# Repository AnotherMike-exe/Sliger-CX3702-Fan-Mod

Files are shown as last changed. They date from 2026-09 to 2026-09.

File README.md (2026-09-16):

# Sliger CX3702 - Fan Mod

*A 3D-printable front panel adaptor that adds triple 120mm fan cooling to the Sliger CX3702 (and compatible face plates).*

<table>
<tr>
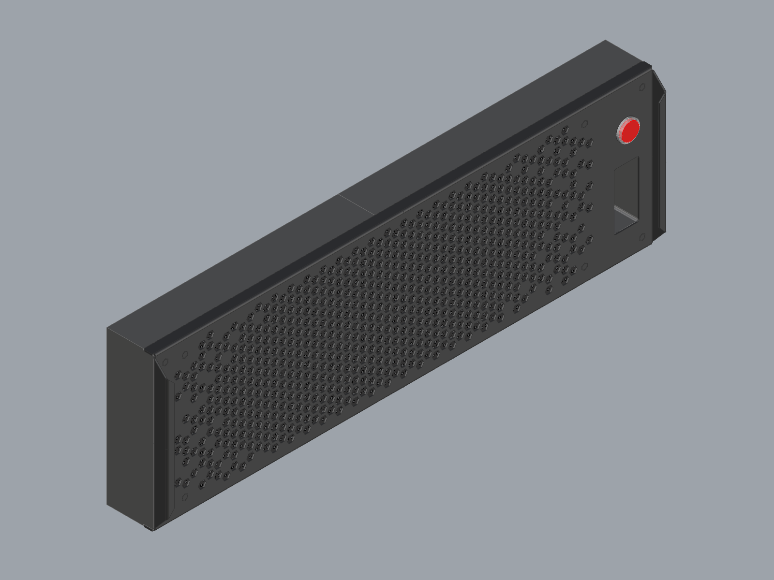
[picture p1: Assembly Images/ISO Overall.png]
Overall view of the assembled fan mod
<td></td>
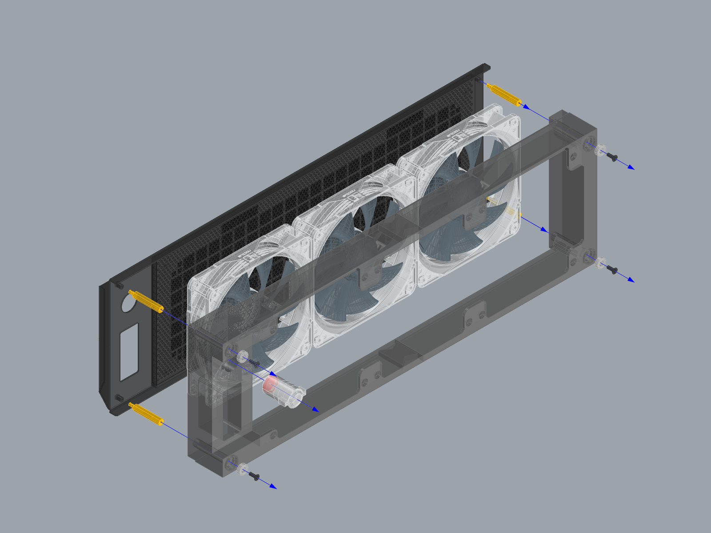
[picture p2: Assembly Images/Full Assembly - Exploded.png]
Exploded view of the full assembly
<td></td>
</tr>
</table>

## Description

This is a 3D-printable spacer for the Sliger CX3702 front panel (and any
Sliger chassis sharing the same face plate and magnetic-washer mounting system). It
allows mounting three 120mm fans, for additional airflow.

## Usage

**Print settings:**

- Frame and standoff parts: PETG, 15% infill, supports enabled.
- Button: multi-material print, PETG/PLA.

**Files:**

| File | Purpose |
| --- | --- |
| `Sliger - CX3702 - Fan Mod.3mf` | Orca Slicer print file. Holds every part, laid out and ready to slice. |
| `Sliger - CX3702 - Fan Mod - Frame.3mf`  | Frame part on its own. |
| `Sliger - CX3702 - Fan Mod - Button.3mf` | Button part on its own. Print as multi-material, PETG/PLA. |
| `Sliger - CX3702 - Fan Mod.stp` | STEP file, for other CAD tools. |
| `Sliger - CX3702 - Fan Mod.stl` | Combined STL mesh, for slicers without STEP or 3MF support. |
| `Sliger - CX3702 - Fan Mod.3dm` | Native Rhino source file. |

Build steps:

1. Remove the four existing magnetic washers and their 3D-printed standoff/housings from the front panel.

2. Pull the magnetic washers out carefully — they're reused later, so avoid snapping them.

3. Install M3 x 30mm standoffs in each location that had a magnet. (I used 20mm and 6mm standoffs stacked, with a longer screw for mine) The cavity only has 30mm between the top of the faceplate's standoff and the top of the hole on the adaptor ring, so plan accordingly if you have long stems on your standoffs.
   
   <table>
   <tr>
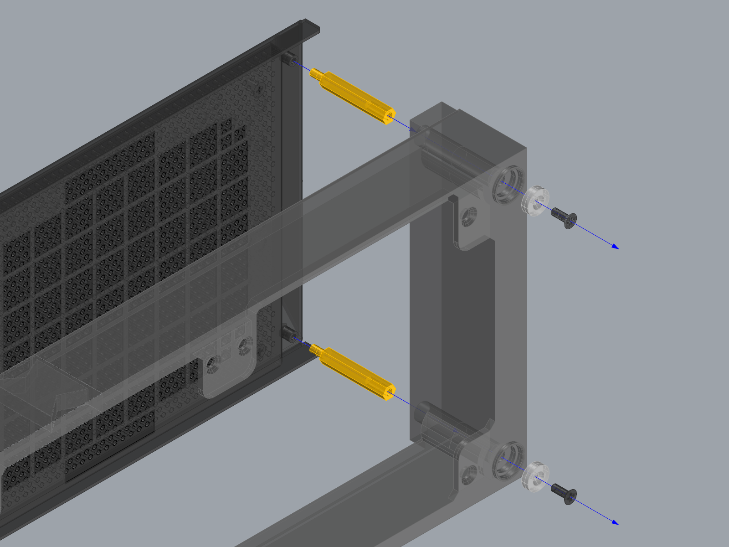
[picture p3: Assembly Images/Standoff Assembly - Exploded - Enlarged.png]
Exploded detail of the standoff assembly
   <td></td>
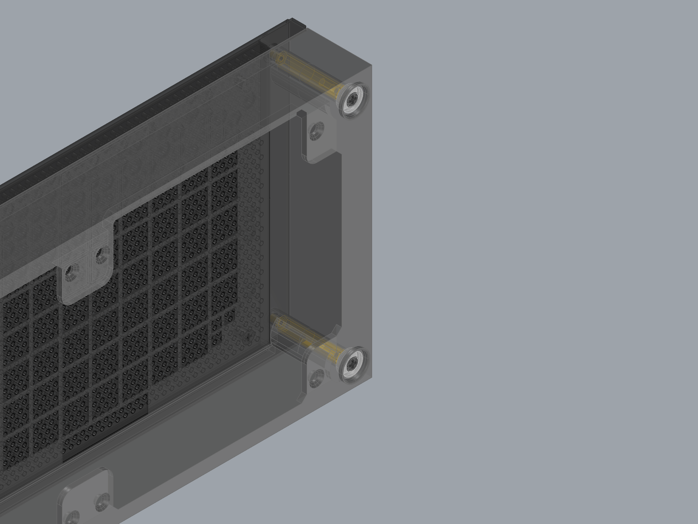
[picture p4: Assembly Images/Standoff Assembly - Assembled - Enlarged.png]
Assembled detail of the standoff assembly
   <td></td>
   </tr>
   </table>

4. Press-fit the magnetic washers into the adaptor frame's washer pockets.

5. Mount the three 120mm fans to the adpator using their included screws.

6. Route the fan cables to the right of the last drive (left of the power button and USB ports) through the hole leading into the chassis. You'll likely need fan extenders to get to the headers with enough slack to still take off the panel easily.

7. Mount the frame to the standoffs — the screws pass through the magnetic washers into the standoffs, the same way the factory frame attached. (May need longer screws depending on your standoffs.)

8. Insert the power button extender into its hole in the adaptor frame.

   <table>
   <tr>
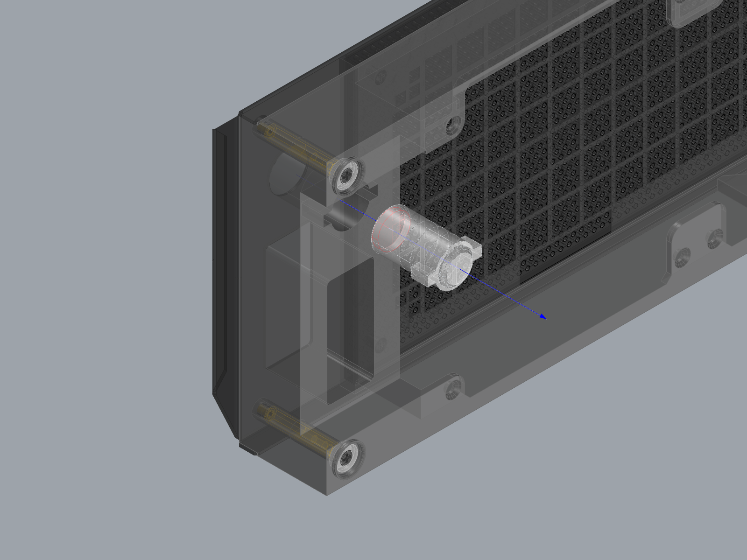
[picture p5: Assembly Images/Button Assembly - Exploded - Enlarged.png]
Exploded detail of the button assembly
   <td></td>
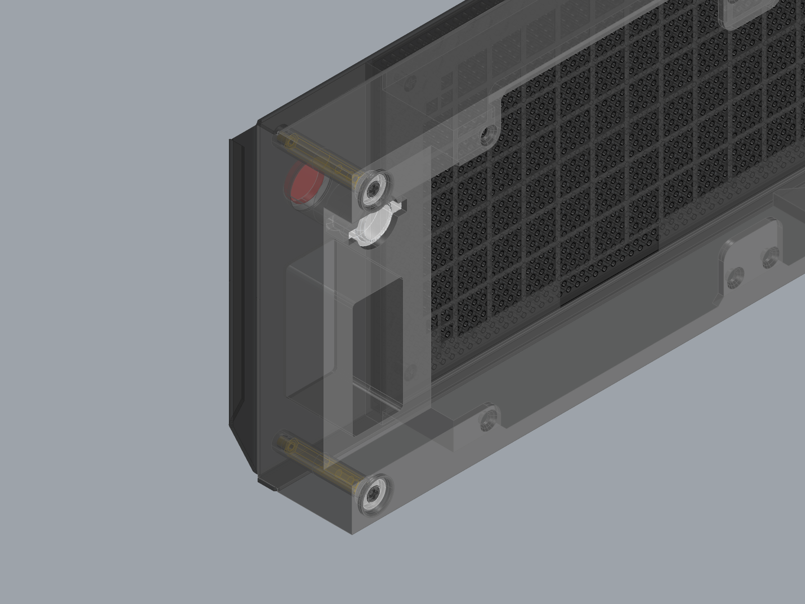
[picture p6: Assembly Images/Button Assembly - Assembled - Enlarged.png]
Assembled detail of the button assembly
   <td></td>
   </tr>
   </table>

9. Attach the assembled frame to the chassis exactly as the original factory frame
   attached.

**Hardware used:**

| Item | Value |
| --- | --- |
| Standoffs | (4) M3 x 30mm Standoffs (shorter works with longer screws — see fit note above) |
| Standoff mounting screws | (4) M3 Phillips head (factory screw, reused) |
| Fans | (3) 120mm |
| Fan Extenders | (3) PC fan cable extenders |

Fan cables route through the chassis pass-through hole between the last drive bay and
the power/USB area — stock fan cables may be too short, so 120mm fan extension cables
are recommended.

Assembly photos are in [`Assembly Images/`](Assembly%20Images/).

## Attributions

- Designed for the Sliger CX3702 chassis and compatible face plates — Sliger is not
  affiliated with this project.
- Released under [CC BY 4.0](LICENSE). Use, modify, and remix freely, for any purpose, with credit to the original designer.

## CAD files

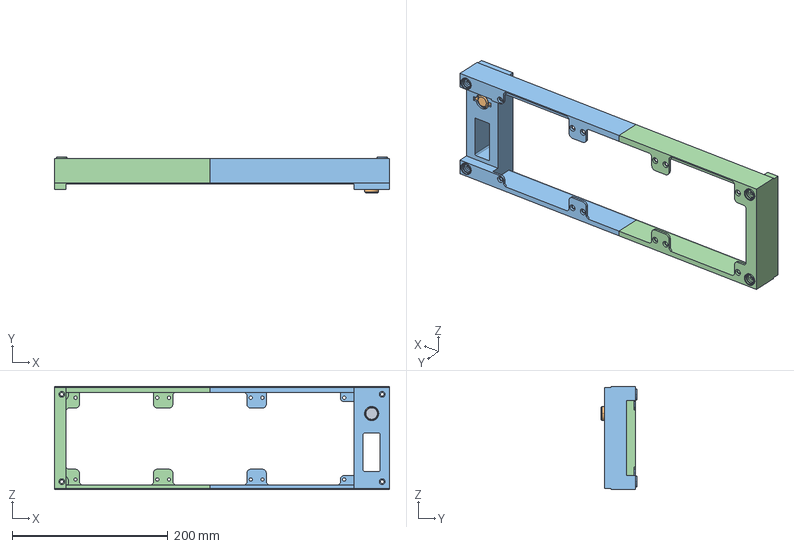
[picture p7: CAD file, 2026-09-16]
Sliger - CX3702 - Fan Mod.stp
430.3 x 46.1 x 132.5 mm

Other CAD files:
Sliger - CX3702 - Fan Mod - Frame.3mf
Sliger - CX3702 - Fan Mod - Button.3mf
Sliger - CX3702 - Fan Mod.3dm
Sliger - CX3702 - Fan Mod.3mf
Sliger - CX3702 - Fan Mod.stl

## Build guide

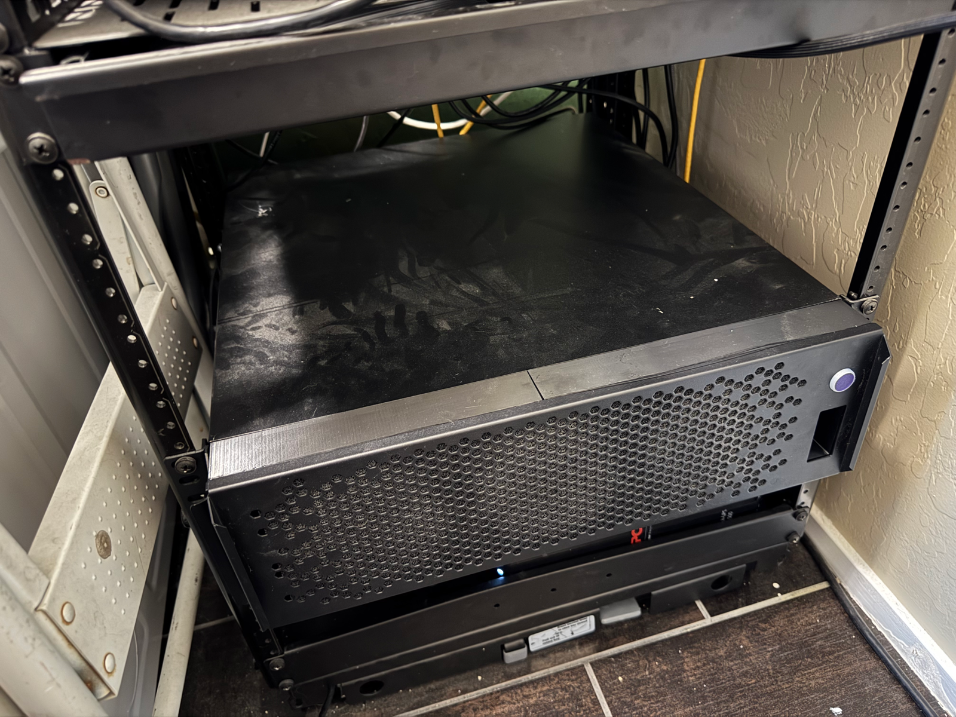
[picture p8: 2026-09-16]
Installed.png

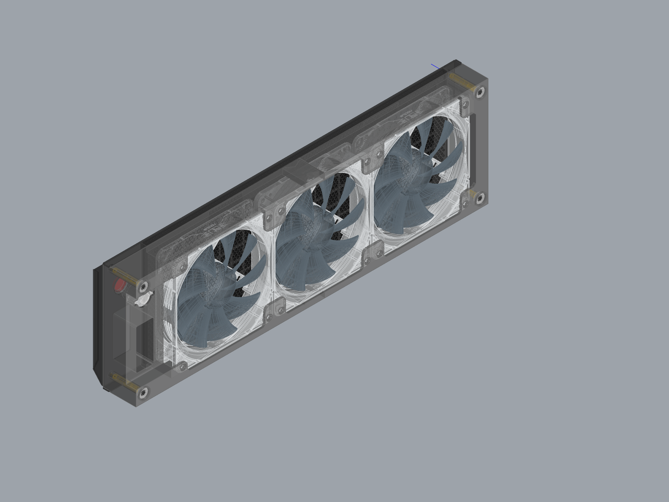
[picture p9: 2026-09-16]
Assembly Images/Full Assembly - Assembled.png

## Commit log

2026-09-16 Initial commit: Sliger CX3702 fan mod front panel adaptor
    3D-printable triple 120mm fan adaptor for the Sliger CX3702 front panel,
    with assembly photos, print files, and CAD source.
    [Sliger - CX3702 - Fan Mod - Button.3mf, Sliger - CX3702 - Fan Mod - Frame.3mf, Sliger - CX3702 - Fan Mod.3dm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]
2026-09-16 Resize Installed.png and PulledOff.png to match assembly photo resolution
    Reason: originals were full-resolution phone photos (13MB and 23MB).
    Resized to 1600px wide to match the Assembly Images set.
2026-09-16 Switch license from CC0 1.0 to CC BY 4.0
    Reason: require attribution to the original designer on reuse.
